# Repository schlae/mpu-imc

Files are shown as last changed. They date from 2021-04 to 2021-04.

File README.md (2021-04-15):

# Roland MPU-IMC Clone

**Warning: There is not enough information in this repository to build your
own card. The microcontroller, IC3, has not been dumped, and the logic in
the gate array chip, IC2, is unknown.**

Based on information available in the MPU-IMC service manual, here is an
exact copy of the board layout. The MIDI Processing Unit is a way to connect
digital musical instruments to a computer using the IBM MCA bus.

Further details on the card are available [here](http://ohlandl.ipv7.net/sound/Roland_MPU-IMC.html).

There are two versions of this board in this repository. The first is a clone
of the stock MPU-IMC. The second is a version that incorporates the circuitry
of the external breakout box normally required for the MPU-IMC, including
the optocoupler required by the MIDI specification.

If you're not sure which board you want to build, choose the modified card.
It has several advantages:

1. You will not need the external Roland breakout box.
2. You can use the card bracket from a common IBM token-ring network card.
3. The DE-9 connector uses the more common footprint.

There are some important caveats with this board set:

1. IC2, the HG62E08, is a gate array chip customized by Roland. Think of it
like a small CPLD but hard coded in ROM. I have no information on the internal
schematic. Beware: not all HG62E08 parts will implement the same exact functions.
Look for a Roland house part number, and make sure they match.
2. IC3, the HD6801VD855P, is a custom mask-programmed microcontroller that
runs the whole show. I have no ROM for this microcontroller.
Before paying for expensive PC boards, make sure you have these chips first!
3. The original (but **NOT** the modded card) has been built and works, see this
[thread on Vogons](https://www.vogons.org/viewtopic.php?f=62&t=77197). The
previous revision accidentally swapped pins 26 and 25 on IC3. This has been
corrected for both the original and the modded card.

For fabrication, use a 2-layer process. You must specify a 30-degree edge bevel,
other angles are probably OK but **do not fab without a bevel at all because
this may damage your MCA bus connectors!** Technically you should get hard gold
for the edge fingers, but that's usually expensive and immersion gold works
just fine.

## MPU-IMC (Plain)

Following are reference materials for your convenience.

[Schematic](https://github.com/schlae/mpu-imc/blob/master/StockCard/RolandMpuImc.pdf)

[Bill of materials](https://github.com/schlae/mpu-imc/blob/master/StockCard/RolandMpuImc.csv)

[Fab files](https://github.com/schlae/mpu-imc/raw/master/StockCard/fab/RolandMpuImc.zip)

**Please note that the DE-9 connector is NOT the standard connector commonly
available**--the distance between the mounting holes and the front plane of
the connector is somewhat larger than usual. You may have to search surplus
sources to find one that will fit, or modify the footprint.

## MPU-IMC (Modified)

Following are reference materials for your convenience.

[Schematic](https://github.com/schlae/mpu-imc/blob/master/ModdedCard/RolandMpuImcMod.pdf)

[Bill of materials](https://github.com/schlae/mpu-imc/blob/master/ModdedCard/RolandMpuImcMod.csv)

[Fab files](https://github.com/schlae/mpu-imc/raw/master/ModdedCard/fab/RolandMpuImcMod.zip)

The DE-9 connector uses the industry standard footprint and is readily available from Mouser.
It's been relocated so that the card bracket from an IBM token ring network card (74F9321)
will fit.

# License

This work is licensed under a Creative Commons Attribution 4.0 International License. See [https://creativecommons.org/licenses/by/4.0/](https://creativecommons.org/licenses/by/4.0/).

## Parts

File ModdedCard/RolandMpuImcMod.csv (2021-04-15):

Item | Qty | Reference(s) | Value | LibPart | Footprint | Datasheet | Mouser
1 | 20 | C1, C3, C4, C6, C7, C8, C9, C10, C11, C12, C13, C14, C15, C18, C19, C24, C26, C29, C31, C35 | 0.1 | Device:C_Small | Roland:C_DISC_200 |  | 581-SR215E104MAT
2 | 4 | C2, C16, C23, C33 | 100/6.3 | Device:CP1_Small | Roland:C_RADIAL_200_P |  | ECA-0JM101B
3 | 1 | C17 | 0.033 | Device:C_Small | Roland:C_DISC_200 |  | 581-SR215C333K
4 | 2 | C20, C30 | 0.0047 | Device:C_Small | Roland:C_DISC_200 |  | 581-SR215C472KAA
5 | 1 | C21 | 0.018 | Device:C_Small | Roland:C_DISC_200 |  | 581-SR215C153KAR
6 | 1 | C22 | 0.0039 | Device:C_Small | Roland:C_DISC_200 |  | 581-SR215C332KAR
7 | 1 | C25 | 22p | Device:C_Small | Roland:C_DISC_200 |  | 581-SR215A220KARTR1
8 | 1 | C27 | 0.0068 | Device:C_Small | Roland:C_DISC_200 |  | 581-SR215C682KAR
9 | 1 | C28 | 0.027 | Device:C_Small | Roland:C_DISC_200 |  | 581-SR211E273M
10 | 1 | C32 | 15p | Device:C_Small | Roland:C_DISC_200 |  | 581-SR211A150KAR
11 | 1 | C34 | 0.001 | Device:C_Small | Roland:C_DISC_200 |  | 581-SR215C102JAR
12 | 2 | C5A1, C5B1 | C_Small | Device:C_Small | Roland:C_DISC_200 |  | 581-SR211A150KAR
13 | 2 | D1, D2 | ? | Device:D_Small_ALT | Roland:D_200 |  | 512-1N4148
14 | 1 | D3 | 1S2473 | Device:D_Small_ALT | Roland:D_200 |  | 512-1N4148
15 | 9 | FL1, FL2, FL3, FL4, FL5, FL6, FL7, FL8, FL9 | EMI_Filter_C | Device:EMI_Filter_C | Roland:FILT_200 |  | 652-EMI101T-RC
16 | 1 | IC1 | LC3517 (or HY6116AP-10) | Roland:LC3517 | Active:DIP254P1524X635-24
17 | 1 | IC2 | HG62E08 | Roland:HG62E08 | Roland:TQFP-64
18 | 1 | IC3 | HD6801VD855P | Roland:HD6801VD855P | Active:DIP254P1524X635-40
19 | 2 | IC4, IC6 | 74LS05 | RolandMpuImcMod-rescue:74LS05 | Active:DIP254P762X635-14 |  | 595-SN74LS05N
20 | 1 | IC5 | 74LS02 | RolandMpuImcMod-rescue:74LS02 | Active:DIP254P762X635-14 |  | 595-SN74LS02N
21 | 1 | IC7 | 74LS32 | RolandMpuImcMod-rescue:74LS32 | Active:DIP254P762X635-14 |  | 595-SN74LS32N
22 | 1 | IC8 | 74LS04 | RolandMpuImcMod-rescue:74LS04 | Active:DIP254P762X635-14 |  | 595-SN74LS04N
23 | 1 | IC9 | 74LS74 | RolandMpuImcMod-rescue:74LS74 | Active:DIP254P762X635-14 |  | SN74LS74AN
24 | 1 | IC10 | 74LS138 | RolandMpuImcMod-rescue:74LS138 | Active:DIP254P762X635-16 |  | 595-SN74LS138N
25 | 1 | IC11 | 74ALS573 | RolandMpuImcMod-rescue:74LS573 | Active:DIP254P762X635-20 |  | 595-SN74ALS573CN
26 | 1 | IC12 | 74LS86_P | Roland:74LS86_P | Active:DIP254P762X635-14 |  | 595-SN74LS86AN
27 | 2 | IC13, IC15 | 74LS688 | RolandMpuImcMod-rescue:74LS688 | Active:DIP254P762X635-20 |  | 595-SN74LS688N
28 | 1 | IC14 | HEF4093B | RolandMpuImcMod-rescue:HEF4093B | Active:DIP254P762X635-14 |  | 595-CD4093BE
29 | 1 | IC16 | 5218 | RolandMpuImcMod-rescue:LM2904 | Active:DIP254P762X635-8 |  | 595-TLV2362IP
30 | 1 | IC17 | H11L1 | RolandMpuImcMod-rescue:H11L1 | Active:DIP254P762X635-6 |  | 512-H11L1TVM
31 | 1 | IRQ1 | Conn_02x06_Odd_Even | RolandMpuImcMod-rescue:Conn_02x06_Odd_Even | Pin_Headers:Pin_Header_Straight_2x06_Pitch2.54mm
32 | 1 | J1 | DB9_Female_MountingHoles | RolandMpuImcMod-rescue:DB9_Female_MountingHoles | Roland:DE-9B |  | 571-2311765-1
33 | 1 | J2 | BUS_MCA | Roland:BUS_MCA | Roland:BUS_MCA_ROLAND
34 | 4 | J3, J4, J5, J6 | Conn_01x01 | RolandMpuImcMod-rescue:Conn_01x01 | Mounting_Holes:MountingHole_3.2mm_M3
35 | 1 | L2 | BL02RN2-R62 | Device:L_Core_Ferrite_Small | Roland:FERR_200 |  | 81-BL03RN2R1P1A
36 | 5 | Q1, Q2, Q3, Q4, Q5 | 2SC1815 | RolandMpuImcMod-rescue:2SC1815 | Roland:Q_200_J |  | 610-2SC1815
37 | 10 | R1, R3, R7, R8, R9, R10, R11, R13, R31, R44 | 4.7K | Device:R_Small | Roland:R_AXIAL_200 |  | 603-CFR-12JB-52-4K7
38 | 8 | R2, R22, R23, R27, R28, R29, R36, R41 | 10K | Device:R_Small | Roland:R_AXIAL_200 |  | 603-CFR-12JB-52-10K
39 | 5 | R4, R5, R17, R25, R30 | 33K | Device:R_Small | Roland:R_AXIAL_200 |  | 603-CFR-12JB-52-33K
40 | 1 | R6 | 1M | Device:R_Small | Roland:R_AXIAL_200 |  | 603-CFR-12JB-52-1M
41 | 1 | R12 | 100 | Device:R_Small | Roland:R_AXIAL_200 |  | 603-CFR-12JB-52-100R
42 | 1 | R14 | 82K | Device:R_Small | Roland:R_AXIAL_200 |  | 603-CFR-12JB-52-82K
43 | 1 | R15 | 22K | Device:R_Small | Roland:R_AXIAL_200 |  | 603-CFR-12JB-52-22K
44 | 1 | R16 | 47K | Device:R_Small | Roland:R_AXIAL_200 |  | 603-CFR-12JB-52-47K
45 | 2 | R18, R20 | 180 | Device:R_Small | Roland:R_AXIAL_200 |  | 603-CFR-12JB-52-180R
46 | 2 | R19, R35 | 1K | Device:R_Small | Roland:R_AXIAL_200 |  | 603-CFR-12JB-52-1K
47 | 1 | R21 | 6.8K | Device:R_Small | Roland:R_AXIAL_200 |  | 603-CFR-12JB-52-6K8
48 | 1 | R24 | 820K | Device:R_Small | Roland:R_AXIAL_200 |  | 603-CFR-12JB-52-820K
49 | 1 | R26 | 470K | Device:R_Small | Roland:R_AXIAL_200 |  | 603-CFR-12JR-52-470K
50 | 2 | R32, R33 | 470 | Device:R_Small | Roland:R_AXIAL_200 |  | 603-CFR-12JB-52-470R
51 | 2 | R34, R43 | 100K | Device:R_Small | Roland:R_AXIAL_200 |  | 603-CFR-12JB-52-100K
52 | 1 | R37 | 270 | Device:R_Small | Roland:R_AXIAL_200 |  | 603-CFR-12JB-52-270R
53 | 3 | R38, R39, R40 | 220 | Device:R_Small | Roland:R_AXIAL_200 |  | 603-CFR-12JB-52-220R
54 | 1 | RA1 | R_Network08 | Device:R_Network08 | Resistors_THT:R_Array_SIP9 |  | 652-4609X-1LF-33K
55 | 1 | X1 | Crystal | Device:Crystal | Roland:Y_200 |  | 520-HCU400-20X

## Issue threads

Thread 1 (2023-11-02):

IC2 6801V0B55P is dumped and more info

matt713, 2023-11-02:
hi Eric, I just want to let you know that 6801V0B55P was dumped 10 years ago, I posted details here:

https://www.vogons.org/viewtopic.php?p=1202055#p1202055

and here:

https://www.vogons.org/viewtopic.php?f=62&t=96744

that dump is the latest known ROM for 6801V0B55P, i.e. version 1.5A, but 6801V0B55P with ROM version 1.4B is confirmed to exist in the wild, at least based on one report:

https://forum.vcfed.org/index.php?threads/roland-mpu-401-eprom-upgrade-1-5a.1238114/

in short that means command 0xAC returns 15 or 14 (respectively version 1.5 or 1.4) and command 0xAD returns 1 or 2 (respectively revision 'A' or 'B' to designate 1.5A or 1.4B) :

https://www.vogons.org/viewtopic.php?p=1202056#p1202056

the retro-computing community believes that 1.5A is the latest Intelligent MIDI firmware version, because that is what is also documented in the "MPU-401 Technical Reference Manual", but now, based on few findings that I made very recently,  I have very strong evidence that there are newer firmware versions (and most importantly those new versions are for Generic 6801 and not for the custom and unobtainable now Roland part 6801V0B55P). it seems those newer firmware versions were introduced to existing devices mainly when an MPU-401 unit was sent back to Roland for a repair, which as you will see makes a lot of sense and here is how I came to that conclusion in chronological order:

thanks to a family friend, now a very old gentleman, who owns that particular MPU-401 unit since like 40 years, I was able to find out that unit has firmware which returns:

0xAC --> 0x15
0xAD --> 0x39

at first I was shocked and confused by that, as there is no known revision 0x39 of firmware 1.5, the only known one is revision 1, i.e. 1.5A.

that's why initially, I was thinking that it has to be some fault like maybe some bits flipped due to aging process where value '01' is stored in the ROM and it became '39', but digging further and further, as it will become clear below, showed me that is not the case and the firmware is really "1.5 revision 39".

What was even more confusing is that based on the label sticker on the bottom of the unit, it shows the unit is from May 1984, i.e. very very early unit, actually one of the earliest possible units - that is over 1 year before Roland released firmware 1.5, which release date is documented in "MPU-401 Technical Reference Manual" to be May 31, 1985.

So, based on "May 1984" date, what it should have is firmware 1.2, but yet it has 1.5 with some strange 0x39 revision number.

OK, it will be long, but digging deeper - I told the owner what I found out and how confusing it is and he told me the unit was sent back to Roland (he cannot recall the exact date or year) for a repair. So, I opened the unit and it was full of surprises:

* what I immediately noticed is the sticker on the EPROM chip - the "2" is stroked-through with an X and "5" is marked, which suggested to me that is how they designated the unit was version 1.2 and it's upgraded to 1.5 during the repair process plus one corner (bottom left) of the sticker shows clear signs of how it was peeled in order to erase it with UV light, finally not one, but several things that seem to add up and to make a lot of sense, here is high-res picture of that EPROM:

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

* Still, I was not sure that is really how they indicate the version on the EPROM sticker, i.e. if for example "5" marked is really supposed to mean version 1.5 and I needed to find some more evidence to support that. So, after spending a lot of time searching for pictures online of another unit with EPROM chip the only one I found is this one:

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

at first that picture added some doubts to me, because it has "7" marked on the EPROM sticker, i.e. if my hypothesis is correct then that should mean firmware version 1.7, which is another unheard thing, but it took me almost no time searching to find that Vogons user "cricket" reported 5 years ago he has unit with ROM version 1.7C, as the post says:

> I can use MPUTHRU.COM on the unit and it prints ROM version 1.7C

https://www.vogons.org/viewtopic.php?p=681558#p681558

even it seems back then no one really paid much attention that version 1.7C is something actually new and unheard.

It's also important that the unit from the picture above with "7" marked on the EPROM is not using 6801V0B55P, but another chip 6801V0A88P, which adds up - different chip, different ROM version, i.e. 1.7C that is not seen on units with 6801V0B55P that are 1.4B or 1.5A.

* further more and it was the final nail in the coffin so to speak is my investigation is that another Vogons user "Artex", reported 10 years ago unit with sticker on the EPROM chip saying "Roland 1.5 DB" :

https://www.vogons.org/viewtopic.php?p=296139#p296139

that to me indicates "version 1.5 revision DB"

here are the 2 important parts of that post:

> two chips missing on the PCB that are present on mine

"Artex" meant by that the EPROM chip and HD74LS04P, which are missing on most MPU-401 units, i.e. those with 6801V0B55P, which has build-in ROM and thus no external EPROM chip.

and "Artex" added:

> The bigger chip says "Roland 1.5 DB"

and between HD74LS04P and the EPROM chip, the bigger one is the EPROM, i.e. "Artex" no doubt is talking about the sticker on the EPROM chip and that it's "Roland 1.5 DB" or "version 1.5 revision DB" (I guess that is the moment when they switched to that new format of the sticker)

Summary and final words:

it seems there are 3 designs:

* 6801V0B55P (build-in ROM, latest known version 1.5A, dumped 10 years ago by the MAME project), in this case the EPROM and HD74LS04P are not populated on the board, but there is space left for them (I guess especially useful when repair is needed).

* 6801V0A88P + HD74LS04P + EPROM : latest known ROM version is 1.7C, unfortunately, dump is not available and Vogons user "cricket" that seems to have such unit is not active for years, i.e. cannot be reached. in any case I don't believe that case is important, because still 6801V0A88P is Roland part and unobtainable now

* the most important and very interesting case - the case of that started my investigation. it's so interesting, because it doesn't use Roland part, but instead off-the-shelf or regular/generic 6801 micro-controller + HD74LS04P + EPROM, i.e. design that is replicate-able. it seems ROM in my case is "version 1.5 revision 39", but there is "version 1.5 revision DB", i.e. the latest known as per the post of user "Artex" on Vogons. Too bad, "Artex" seems is not active for years on Vogons and no dump of that "version 1.5 revision DB".

Another interesting thing is that disassembling 6801V0B55P ROM 1.5A and the dump I made of "version 1.5 revision 39" from that repaired unit with the regular/generic 6801 micro-controller shows different instructions are used - few examples:

LDAB (1.5A) --> LDB (1.5 rev 39)
LDAA (1.5A) --> LDA (1.5 rev 39)
STAA (1.5A) --> STA (1.5 rev 39)

and so and so on. Now, I know nothing about 680x-assembler and it took me a lot of searching to find out this:

http://datapipe-blackbeltsystems.com/windows/flex/asm4.html

which states:

> SOURCE FORM: LDA (P); LDB (P);
> 6800 ALTERNATES: LDAA (P); LDAB (P);

and

> SOURCE FORM: STA (P);
> 6800 ALTERNATES: STAA (P);

or it seems "1.5 rev 39" is compiled as 6809-code, which I don't really get, because the PCB with that ROM has off-the-shelf regular/generic 6801 micro-controller. In any case, it seems as part of repairs (and I guess lack of stock of those custom Roland 6801V0B55P or 6801V0A88P parts), they replaced the chip with regular/generic 6801 and built that "1.5 rev 39" firmware. Something almost like Roland hacked themselves. Again, it's too bad Vogons user "Artex" is unreachable and we cannot learn more about that "version 1.5 revision DB" unit and what chip it has inside.
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
schlae, 2023-11-09:
wow, incredible research! it should be possible to reimplement the HG62E08R10FS using a CPLD, or perhaps a small FPGA. the next step would be to reverse engineer and comment the firmware to (as you mentioned) understand how the gate array is supposed to work.

matt713, 2023-11-20:
please, if I can further help with anything feel free to emails me: matura713@gmail.com.

schlae, 2023-11-21:
i won't be able to look into this for quite some time since i am busy with other projects. but feel free to try your hand at reverse engineering the firmware that you've dumped.

matt713, 2023-11-21:
actually, the MAME source code:

https://github.com/mamedev/mame/blob/master/src/devices/machine/mpu401.cpp

gives good idea how at least the gate array and the 6801 micro-controller are communicating. what I am not sure is if the speed in their code is correct, because MAME code says "/* 4 MHz as per schematics */", but the 6801 micro-controller in my repaired unit is 1MHz. maybe, there is some internal divider or something, i.e. externally it's 4MHz and internally 1MHz, not sure. anyway, just making a note, it's all subject to further in-depth analysis of the firmware code.

matt713, 2023-11-29:
The following is off-topic when it comes to MPU-IMC preservation, but I want to document it here and keep all the information in the same place, because it's on-topic when it comes to designs that were used.

So, I found 4th design, apart from the 3 designs I mentioned in the previous posts ("6801V0B55P with build-in ROM", "6801V0A88P + HD74LS04P + EPROM" and "Generic 6801 MCU + HD74LS04P + EPROM) - that 4th design is highly integrated and I found it in MPU-401N unit that I purchased very cheaply (less than 20 USD) with the sole intent to see what's inside it, because without the very special 110-pin cable that MPU-401N unit needs it's not really usable plus very few NEC PC-98 laptops have such 110-pin connector in the first place.

So, here is what's inside:
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

It's all highly integrated and concentrated in that big chip with the 3 dies located in the right bottom corner of the PCB.

After I de-soldered that chip:
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

it became clear it's "15239182" - that is not only silk-screened on the PCB under the IC, but I can see it when I hold the IC against light as well. BTW, that big capacitor-looking thingy on the bottom side of  "15239182" IC is actually 4MHz crystal - it's written on one of its sides, other small SMD components on the bottom side of "15239182" are nothing special - just few regular resistors and capacitor.

So, after some searching it turned out "15239182" is documented in SCC-1 Service Manual ("ROLAND_SCC-1_SERVICE_NOTES.pdf") and it's described as:

`MPU Core: a hybrid IC integrating the CPU of MPU-PC98II, gate array and RAM. Its operation is fully compatible with MPU-401`

now what is most interesting and the main finding is that makes possible and allows "**Converting MPU-401N to an ISA card**", because SCC-1 Service Manual contains pin-out of "15239182" and even better - full schematic how "15239182" is wired to an ISA bus. it's very simple circuit - essentially, it's consist just of 74HC688 used for port address decoding and "15239182". So, to make ISA Intelligent MPU-401 card around "15239182" requires very few components, because basically "15239182" is System-on-Chip when it comes to  Intelligent MPU-401 processing.

Basically, that 4th design opens up the possibility of making ISA card with recycling mostly useless MPU-401N and use them for a source of "15239182". After all MPU-401N is not very usable otherwise, because its use is limited to very few NEC PC-98 laptops and it requires unobtainable now (and the pin-out is not available anywhere, AFAIK) 110-pin connector cable. So, best use of MPU-401N is converting it to an ISA card using it just as a donor for "15239182" IC and utilizing the schematic from SCC-1 Service Manual. I am planning to make such ISA card for myself, just as a proof-of-concept.

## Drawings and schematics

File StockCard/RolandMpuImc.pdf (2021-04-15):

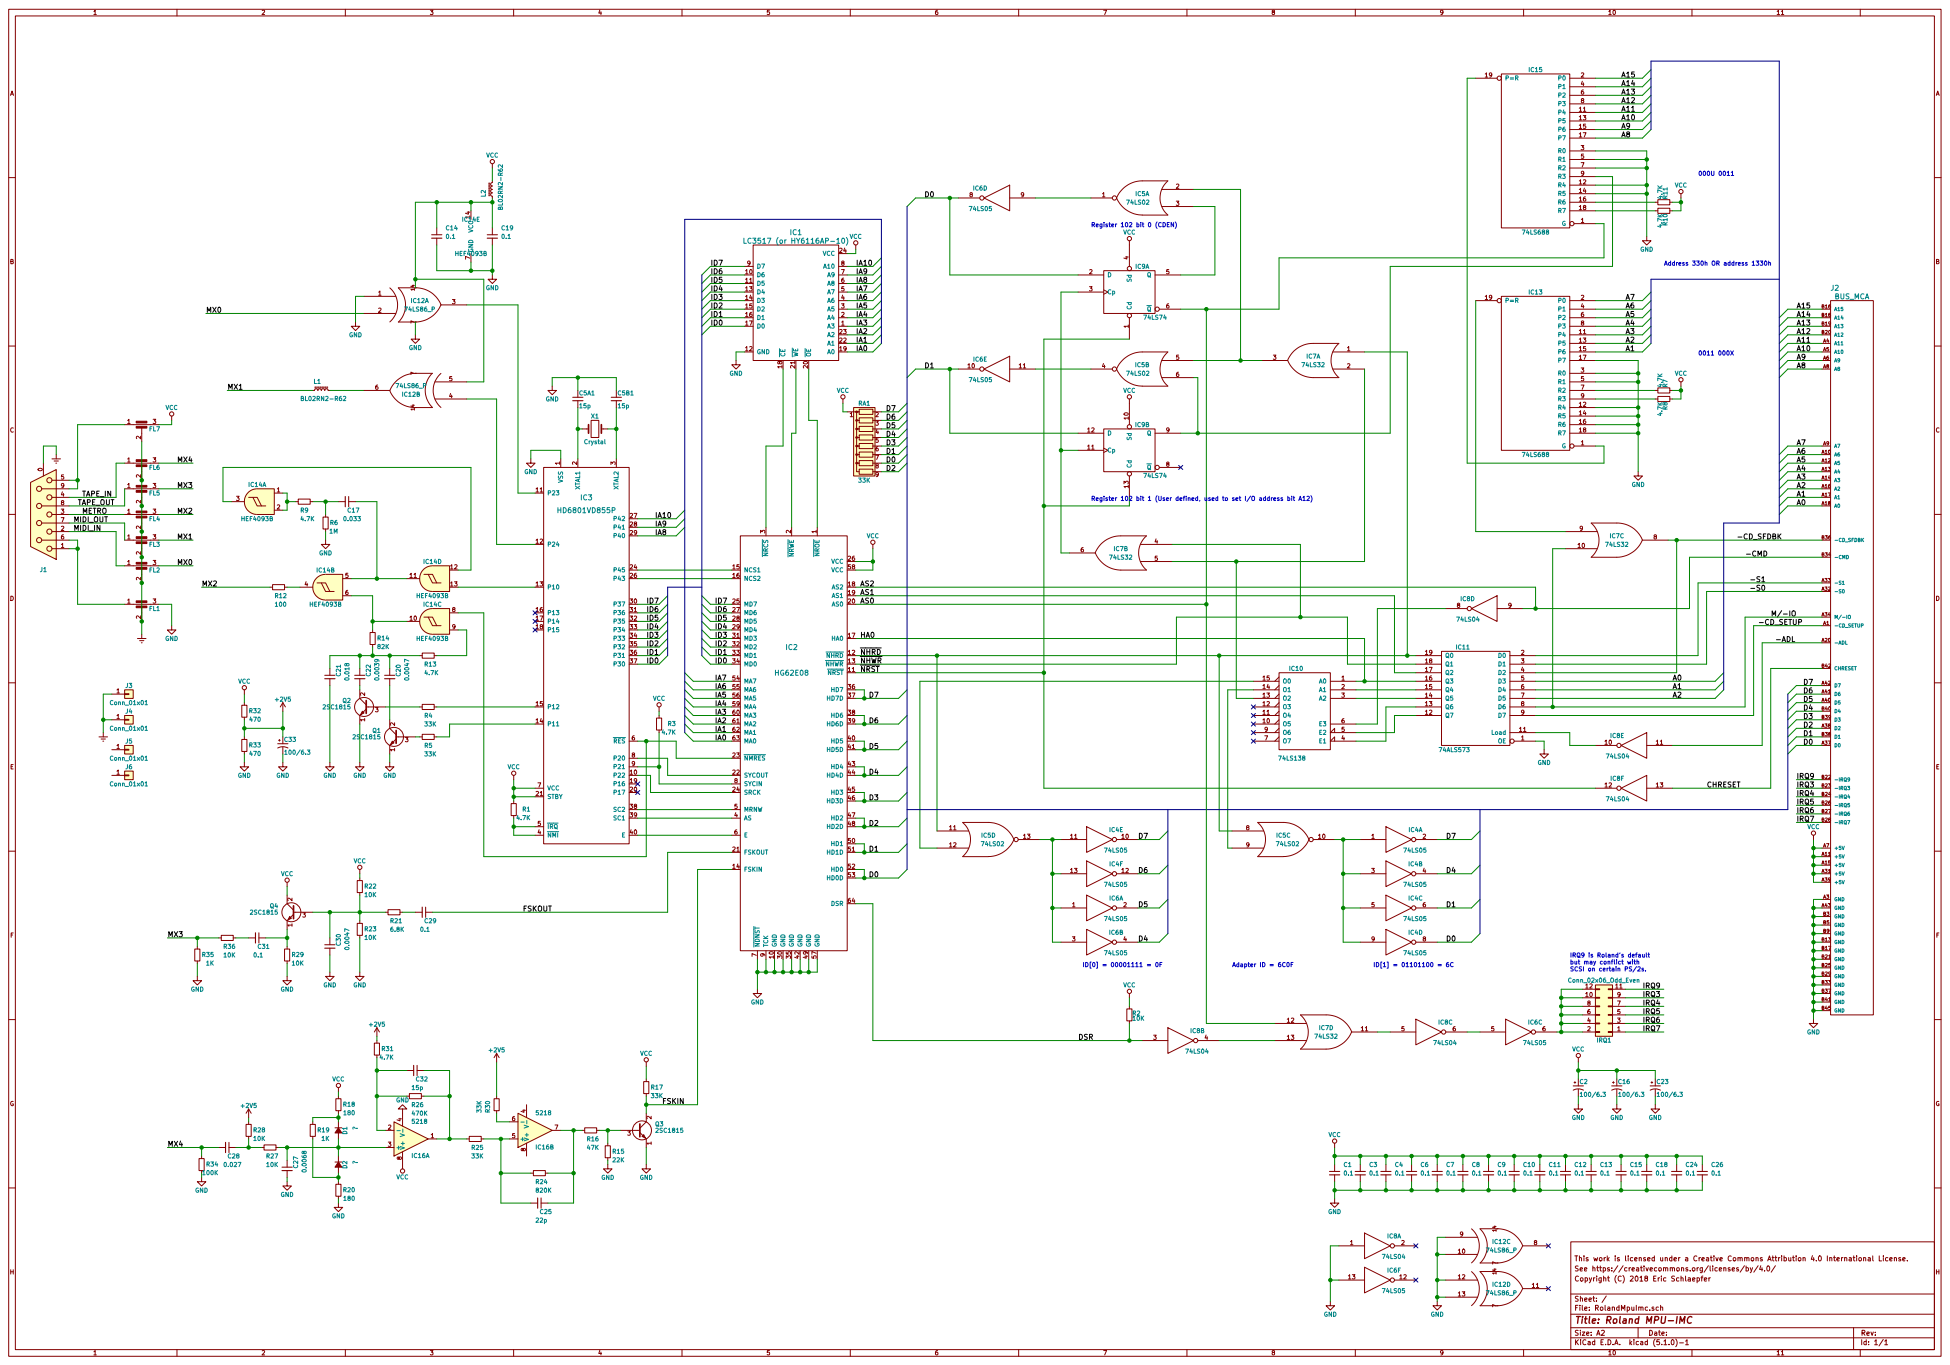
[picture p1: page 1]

ID6 | IA9
ID5 | IA8

ID3 | IA6
ID2 | IA5
ID1 | IA4

Register 102 bit 1 (User defined, used to set I/O address bit A12)

1 GND 10 NRST 11 NHRD 12 NHWR 13 FSKIN 14 NCS1 15 NCS2 16 HA0 17 AS2 18 AS1 19 NRWE

2 AS0 20 FSKOUT 21 SYCOUT 22 NMRES 23 SRCK 24 MD7 25 VCC 26 MD6 27 MD5 28 MD4 29 NRCS

3 GND 30 MD3 31 MD2 32 MD1 33 MD0 34 GND 35 HD7 36 HD7D 37 HD6 38 HD6D 39 AS 4 HD5 40 HD5D 41 GND 42 HD4 43 HD4D 44 HD3 45 HD3D 46 HD2 47 HD2D 48 GND 49 MRNW 5 HD1 50 HD1D 51 HD0 52 HD0D 53 MA7 54 MA6 55 MA5 56 GND 57 VCC 58 MA4 59 E

IRQ9 is Roland's default but may conflict with SCSI on certain PS/2s.

See https://creativecommons.org/licenses/by/4.0/ This work is licensed under a Creative Commons Attribution 4.0 International License.
File: RolandMpuImc.sch Sheet: / Copyright (C) 2018 Eric Schlaepfer

Id: 1/1 Title: Roland MPU-IMC

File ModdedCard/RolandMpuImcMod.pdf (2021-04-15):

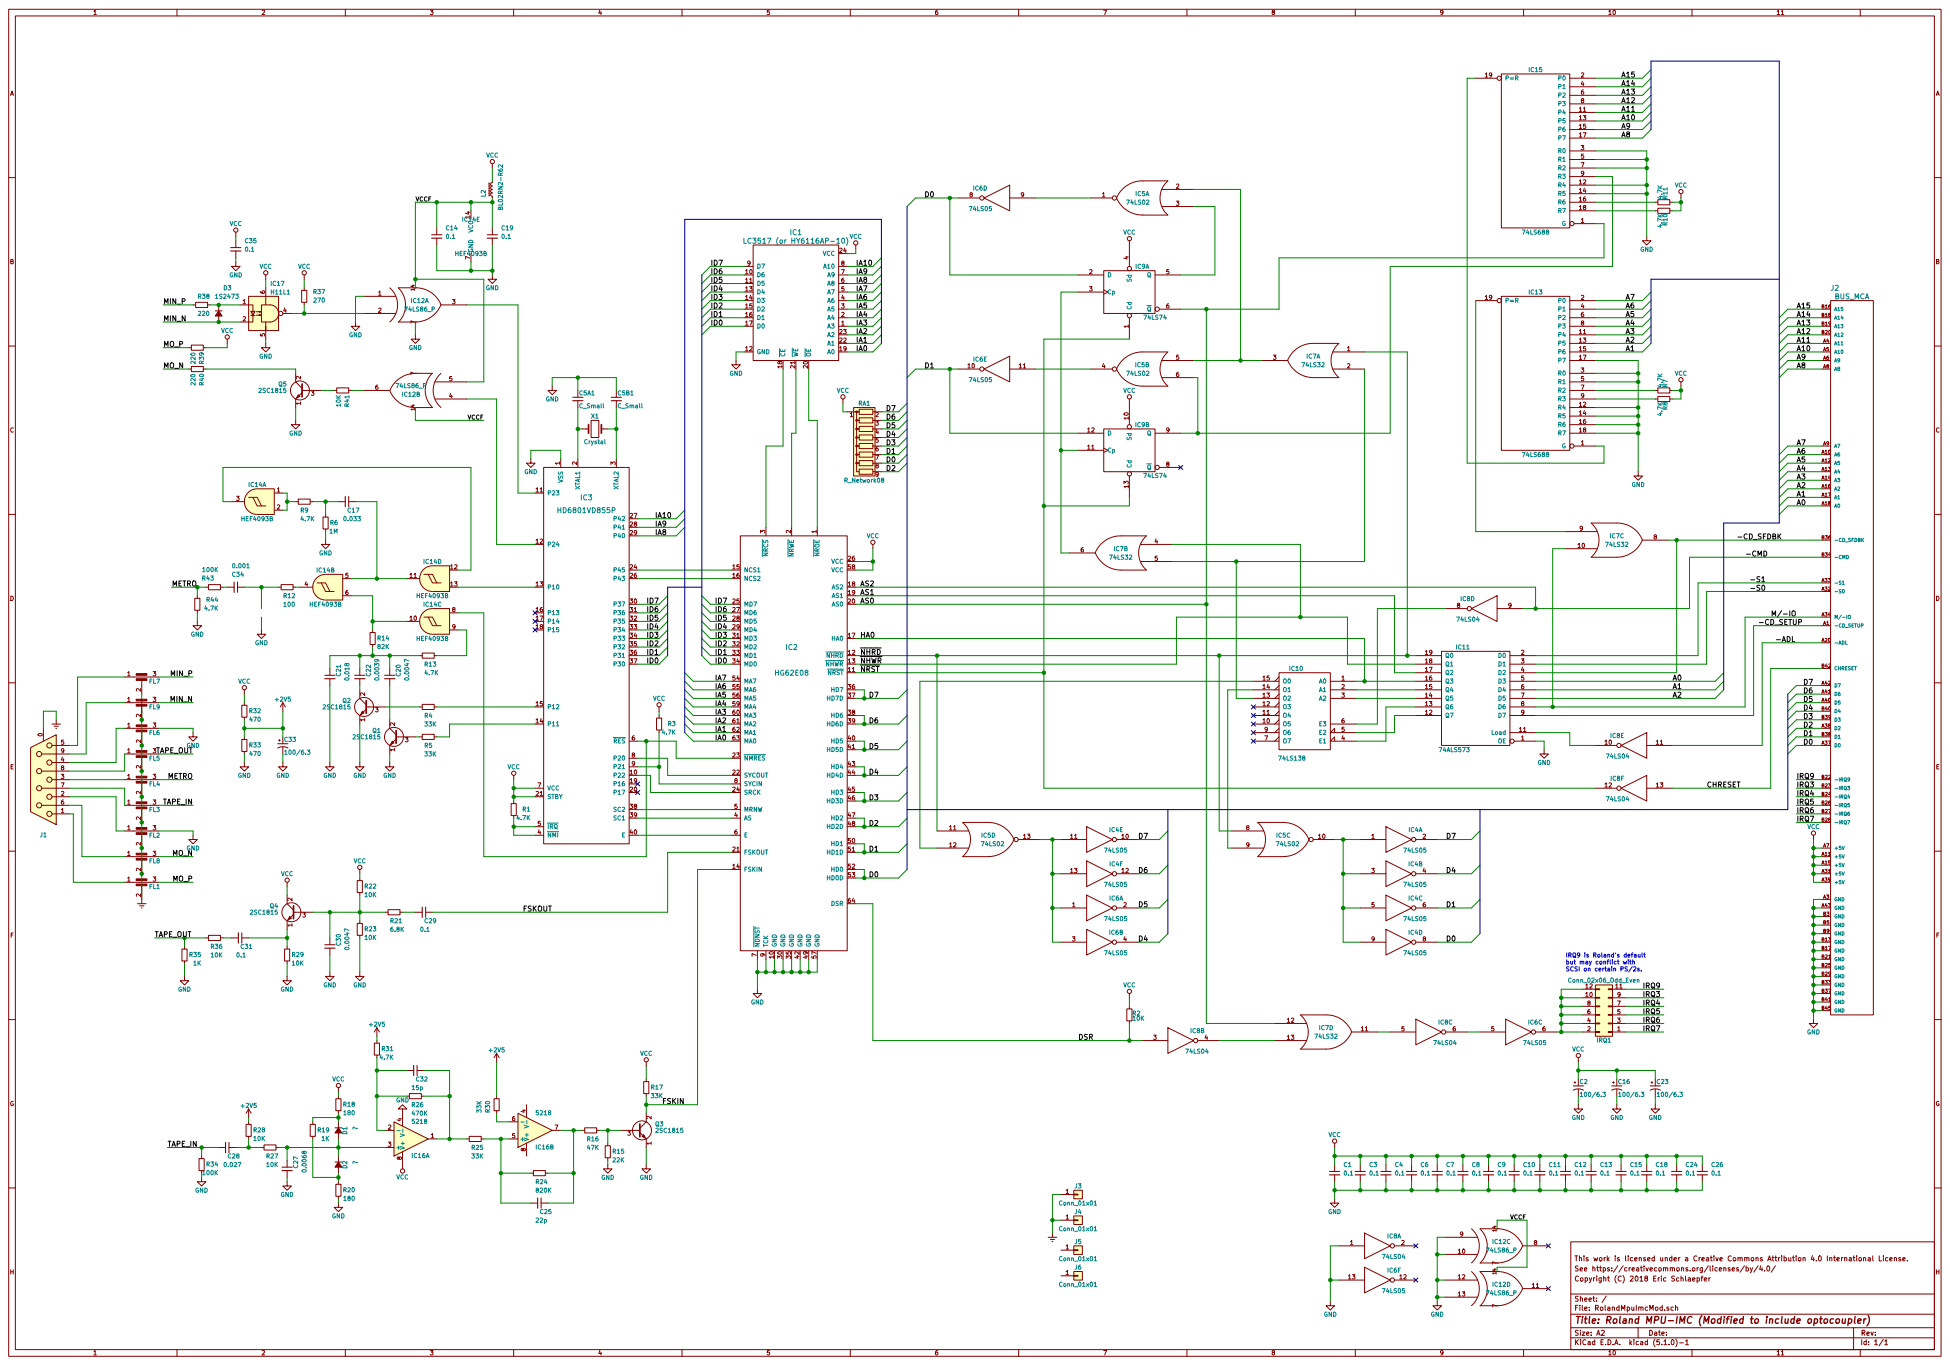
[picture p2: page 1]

ID6 | IA9
ID5 | IA8

ID1 | IA4
ID0 | IA3

IRQ9 is Roland's default but may conflict with SCSI on certain PS/2s.

File: RolandMpuImcMod.sch Sheet: / Copyright (C) 2018 Eric Schlaepfer

Id: 1/1 Title: Roland MPU-IMC (Modified to include optocoupler)

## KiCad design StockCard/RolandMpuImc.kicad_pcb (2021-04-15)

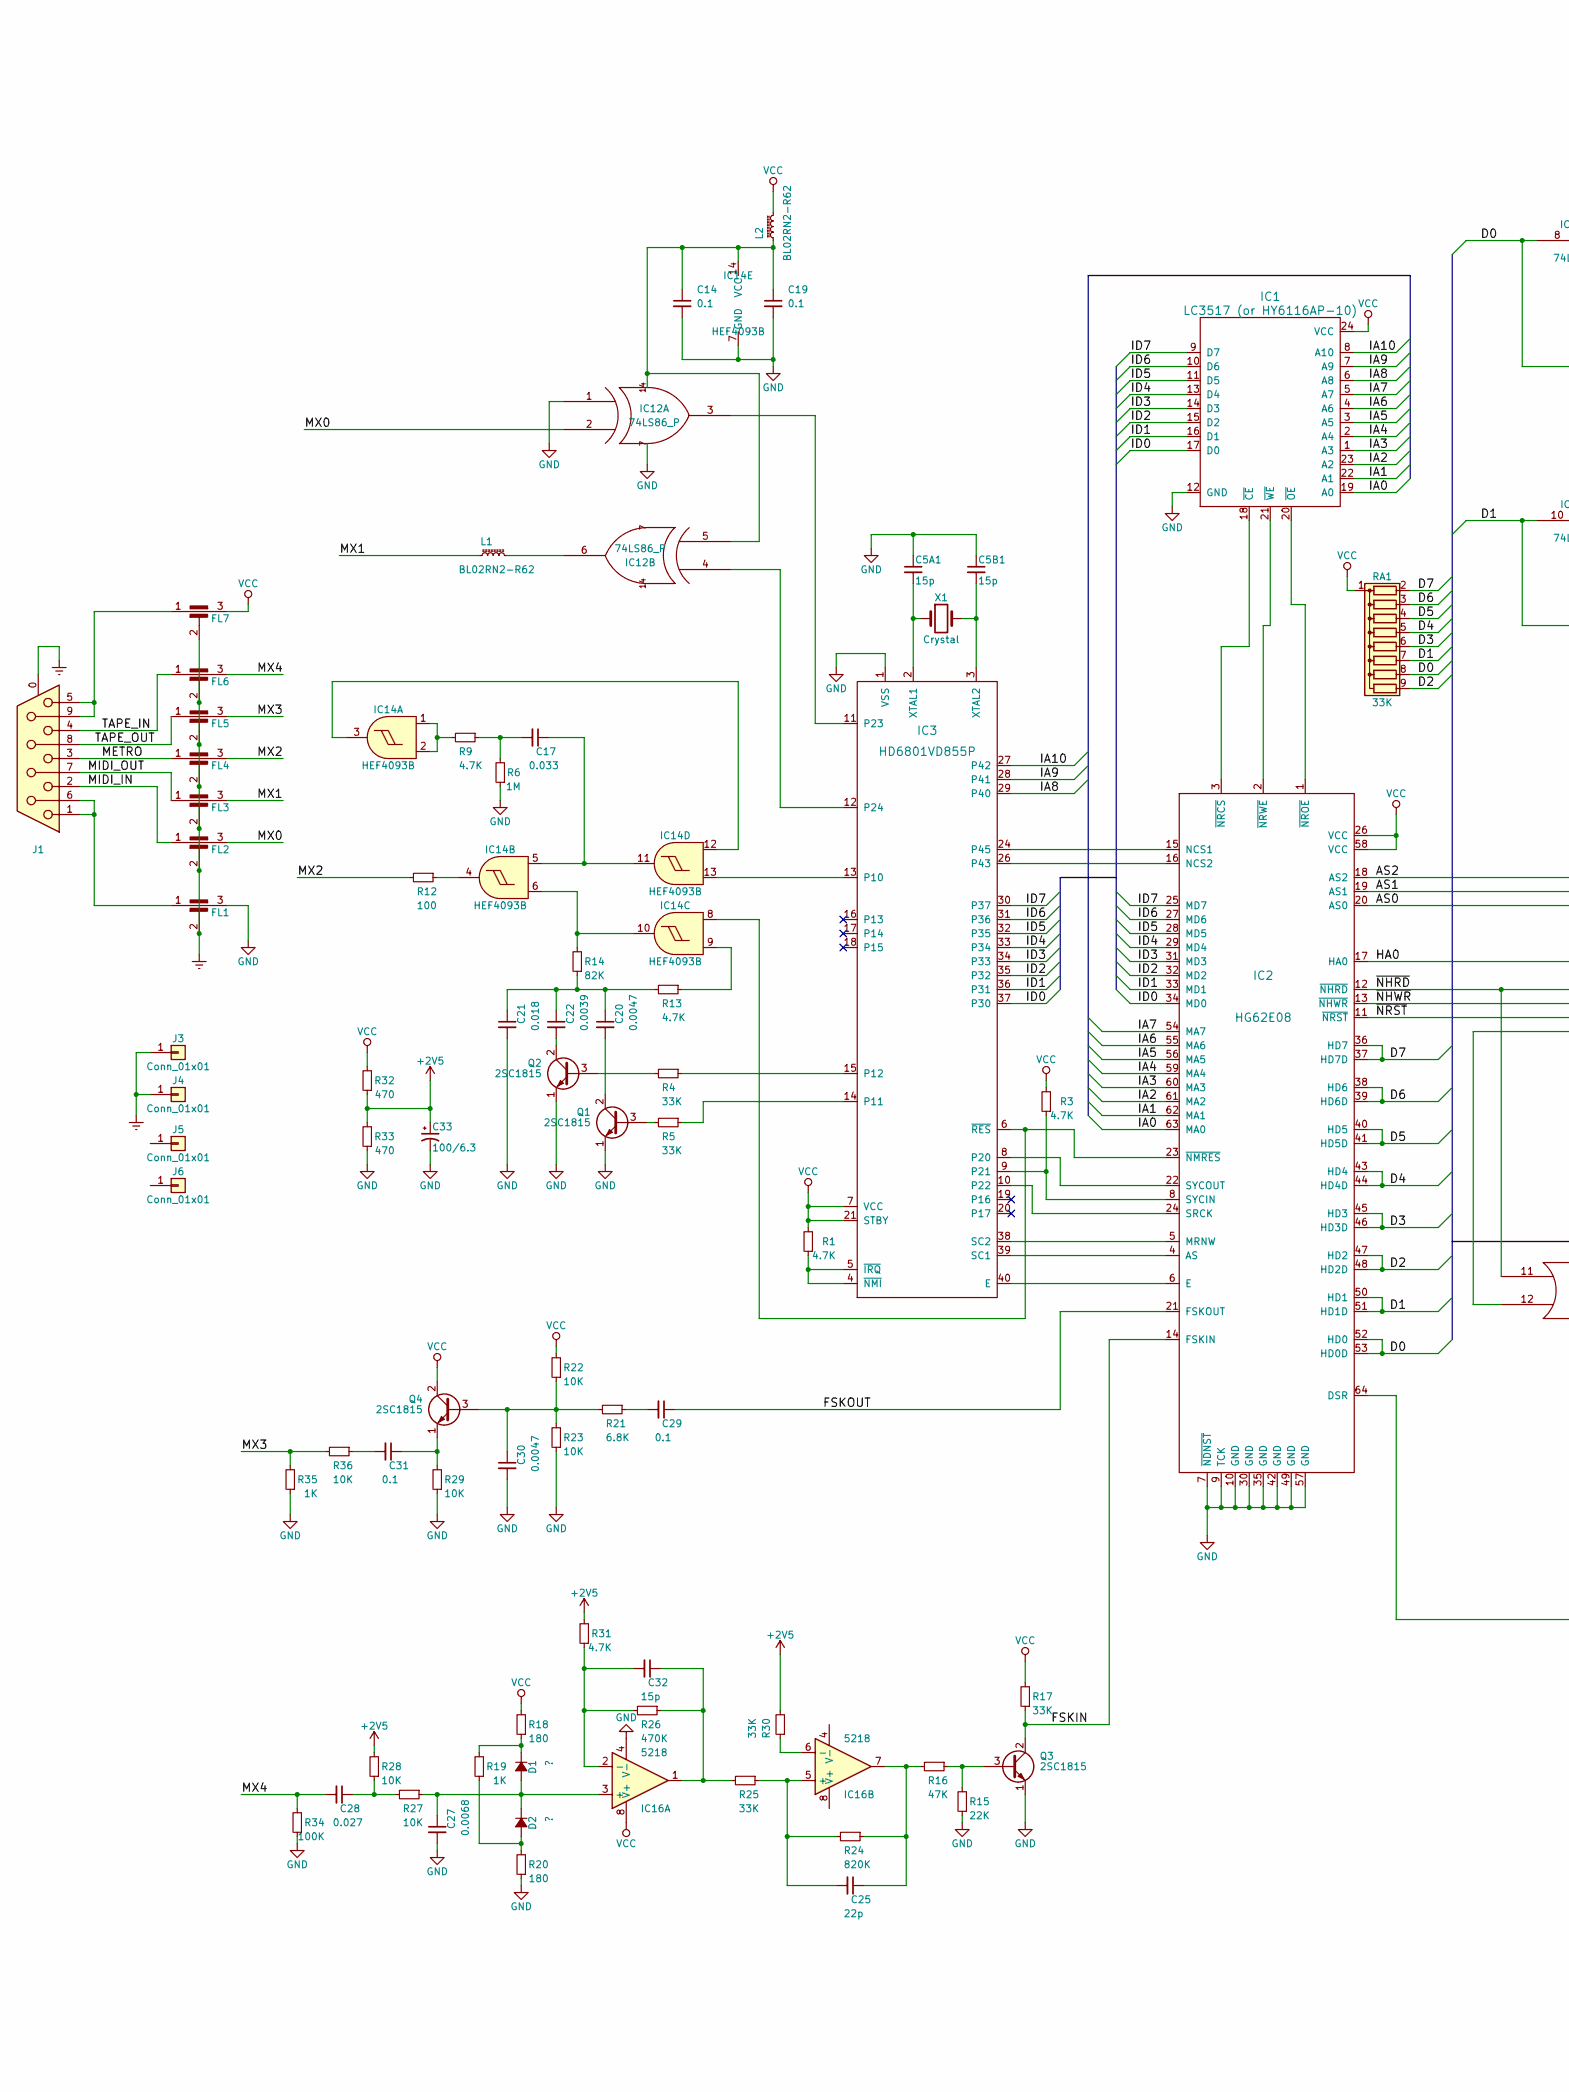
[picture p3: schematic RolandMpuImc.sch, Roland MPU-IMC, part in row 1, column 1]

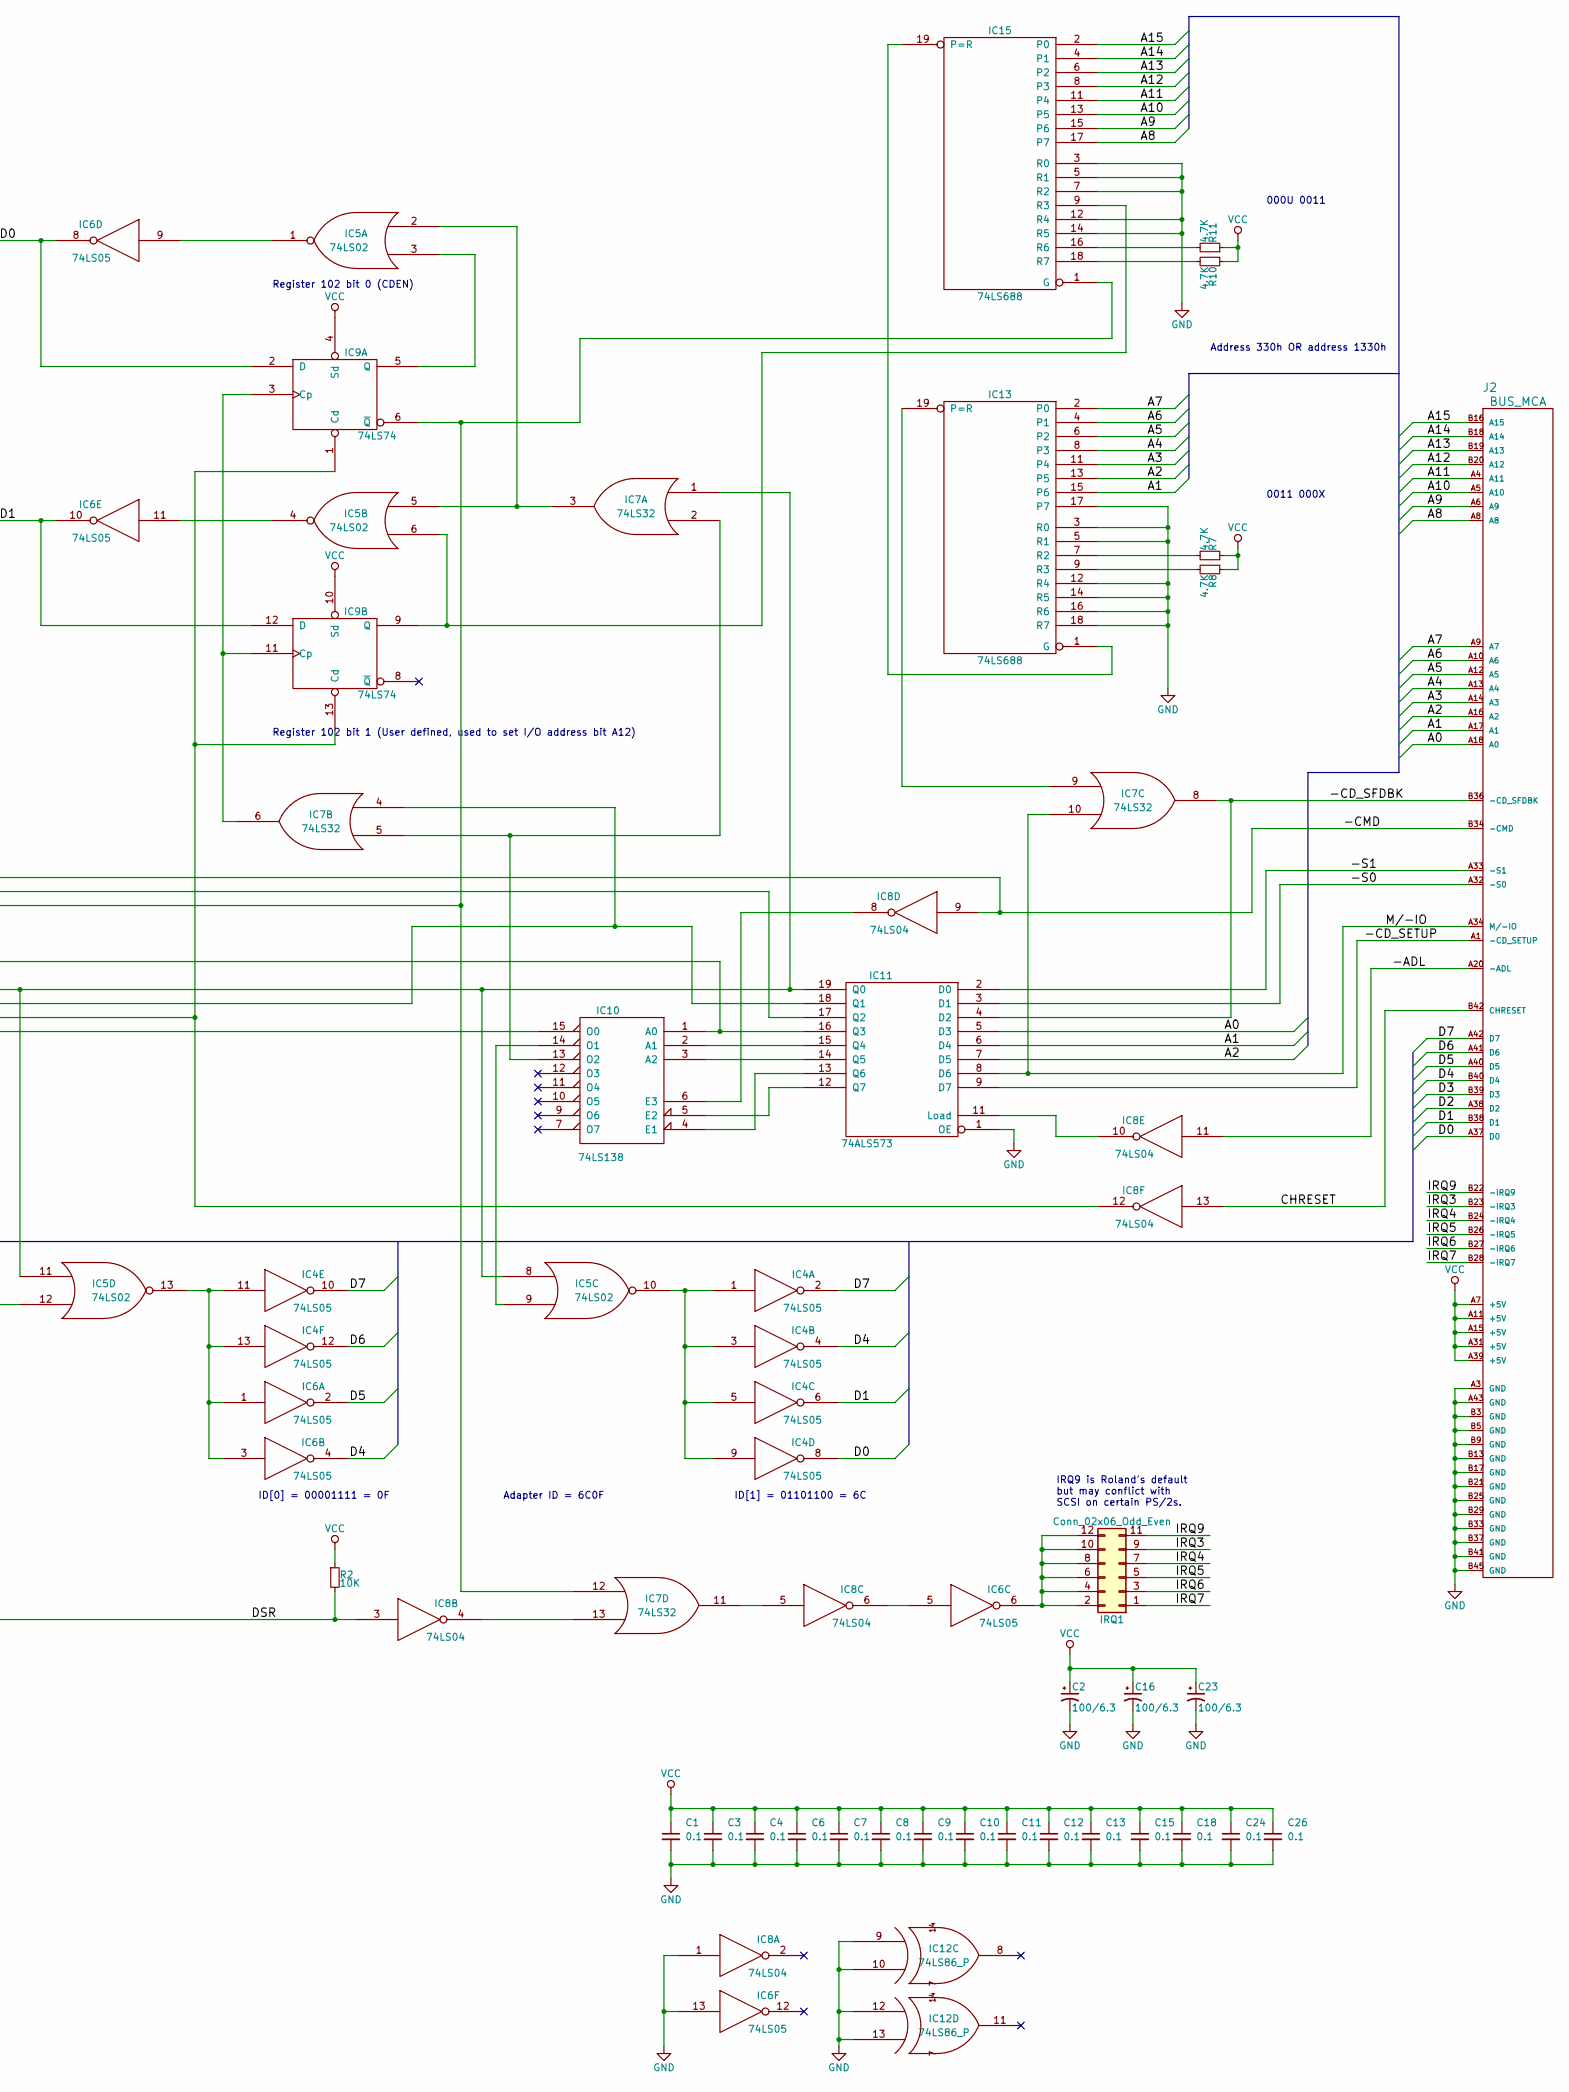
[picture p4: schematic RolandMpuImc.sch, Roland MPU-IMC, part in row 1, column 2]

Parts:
C1, C3, C4, C6, C7, C8, C9, C10, C11, C12, C13, C14, C15, C18, C19, C24, C26, C29, C31: 0.1; C_DISC_200; Mouser 581-SR215E104MAT
C2, C16, C23, C33: 100/6.3; C_RADIAL_200_P; Mouser ECA-0JM101B
C5A1, C5B1, C32: 15p; C_DISC_200; Mouser 581-SR211A150KAR
C17: 0.033; C_DISC_200; Mouser 581-SR215C333K
C20, C30: 0.0047; C_DISC_200; Mouser 581-SR215C472KAA
C21: 0.018; C_DISC_200; Mouser 581-SR215C153KAR
C22: 0.0039; C_DISC_200; Mouser 581-SR215C332KAR
C25: 22p; C_DISC_200; Mouser 581-SR215A220KARTR1
C27: 0.0068; C_DISC_200; Mouser 581-SR215C682KAR
C28: 0.027; C_DISC_200; Mouser 581-SR211E273M
D1, D2: ?; D_200; Mouser 512-1N4148
FL1, FL2, FL3, FL4, FL5, FL6, FL7: EMI_Filter_C; FILT_200; Mouser 652-EMI101T-RC
IC1: LC3517 (or HY6116AP-10); DIP254P1524X635-24
IC2: HG62E08; TQFP-64
IC3: HD6801VD855P; DIP254P1524X635-40
IC4, IC6: 74LS05; DIP254P762X635-14; Mouser 595-SN74LS05N
IC5: 74LS02; DIP254P762X635-14; Mouser 595-SN74LS02N
IC7: 74LS32; DIP254P762X635-14; Mouser 595-SN74LS32N
IC8: 74LS04; DIP254P762X635-14; Mouser 595-SN74LS04N
IC9: 74LS74; DIP254P762X635-14; Mouser SN74LS74AN
IC10: 74LS138; DIP254P762X635-16; Mouser 595-SN74LS138N
IC11: 74ALS573; DIP254P762X635-20; Mouser 595-SN74ALS573CN
IC12: 74LS86_P; DIP254P762X635-14; Mouser 595-SN74LS86AN
IC13, IC15: 74LS688; DIP254P762X635-20; Mouser 595-SN74LS688N
IC14: HEF4093B; DIP254P762X635-14; Mouser 595-CD4093BE
IC16: 5218; DIP254P762X635-8; Mouser 595-TLV2362IP
IRQ1: Conn_02x06_Odd_Even; Pin_Header_Straight_2x06_Pitch2.54mm
J1: DB9_Female_MountingHoles; DE-9; Mouser 523-L77SDE09S1ACH4F
J2: BUS_MCA; BUS_MCA_ROLAND
J3, J4, J5, J6: Conn_01x01; MountingHole_3.2mm_M3
L1, L2: BL02RN2-R62; FERR_200; Mouser 81-BL03RN2R1P1A
Q1, Q2, Q3, Q4: 2SC1815; Q_200_J; Mouser 610-2SC1815
R1, R3, R7, R8, R9, R10, R11, R13, R31: 4.7K; R_AXIAL_200; Mouser 603-CFR-12JB-52-4K7
R2, R22, R23, R27, R28, R29, R36: 10K; R_AXIAL_200; Mouser 603-CFR-12JB-52-10K
R4, R5, R17, R25, R30: 33K; R_AXIAL_200; Mouser 603-CFR-12JB-52-33K
R6: 1M; R_AXIAL_200; Mouser 603-CFR-12JB-52-1M
R12: 100; R_AXIAL_200; Mouser 603-CFR-12JB-52-100R
R14: 82K; R_AXIAL_200; Mouser 603-CFR-12JB-52-82K
R15: 22K; R_AXIAL_200; Mouser 603-CFR-12JB-52-22K
R16: 47K; R_AXIAL_200; Mouser 603-CFR-12JB-52-47K
R18, R20: 180; R_AXIAL_200; Mouser 603-CFR-12JB-52-180R
R19, R35: 1K; R_AXIAL_200; Mouser 603-CFR-12JB-52-1K
R21: 6.8K; R_AXIAL_200; Mouser 603-CFR-12JB-52-6K8
R24: 820K; R_AXIAL_200; Mouser 603-CFR-12JB-52-820K
R26: 470K; R_AXIAL_200; Mouser 603-CFR-12JR-52-470K
R32, R33: 470; R_AXIAL_200; Mouser 603-CFR-12JB-52-470R
R34: 100K; R_AXIAL_200; Mouser 603-CFR-12JB-52-100K
RA1: 33K; R_Array_SIP9; Mouser 652-4609X-1LF-33K
X1: Crystal; Y_200; Mouser 520-HCU400-20X

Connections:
+2V5: C33.1, R28.2, R30.2, R31.2, R32.1, R33.2
/-ADL: IC8.11, J2.A20 (-ADL)
/-CD_SETUP: IC11.9 (D7), J2.A1 (-CD_SETUP)
/-CD_SFDBK: IC7.8, IC11.4 (D2), J2.B36 (-CD_SFDBK)
/-CMD: IC2.18 (AS2), IC8.9, J2.B34 (-CMD)
/-S0: IC11.3 (D1), J2.A32 (-S0)
/-S1: IC11.2 (D0), J2.A33 (-S1)
/A0: IC11.5 (D3), J2.A18 (A0)
/A1: IC11.6 (D4), IC13.15 (P6), J2.A17 (A1)
/A2: IC11.7 (D5), IC13.13 (P5), J2.A16 (A2)
/A3: IC13.11 (P4), J2.A14 (A3)
/A4: IC13.8 (P3), J2.A13 (A4)
/A5: IC13.6 (P2), J2.A12 (A5)
/A6: IC13.4 (P1), J2.A10 (A6)
/A7: IC13.2 (P0), J2.A9 (A7)
/A8: IC15.17 (P7), J2.A8
/A9: IC15.15 (P6), J2.A6 (A9)
/A10: IC15.13 (P5), J2.A5 (A10)
/A11: IC15.11 (P4), J2.A4 (A11)
/A12: IC15.8 (P3), J2.B20 (A12)
/A13: IC15.6 (P2), J2.B19 (A13)
/A14: IC15.4 (P1), J2.B18 (A14)
/A15: IC15.2 (P0), J2.B16 (A15)
/AS0: IC2.20 (AS0), IC7.12, IC9.6 (~Q), IC15.1 (G)
/AS1: IC2.19 (AS1), IC11.17 (Q2)
/CHRESET: IC8.13, J2.B42 (CHRESET)
/D0: IC2.52 (HD0), IC2.53 (HD0D), IC4.8, IC6.8, IC9.2 (D), J2.A37 (D0), RA1.8 (R7)
/D1: IC2.50 (HD1), IC2.51 (HD1D), IC4.6, IC6.10, IC9.12 (D), J2.B38 (D1), RA1.7 (R6)
/D2: IC2.47 (HD2), IC2.48 (HD2D), J2.A38 (D2), RA1.9 (R8)
/D3: IC2.45 (HD3), IC2.46 (HD3D), J2.B39 (D3), RA1.6 (R5)
/D4: IC2.43 (HD4), IC2.44 (HD4D), IC4.4, IC6.4, J2.B40 (D4), RA1.5 (R4)
/D5: IC2.40 (HD5), IC2.41 (HD5D), IC6.2, J2.A40 (D5), RA1.4 (R3)
/D6: IC2.38 (HD6), IC2.39 (HD6D), IC4.12, J2.A41 (D6), RA1.3 (R2)
/D7: IC2.36 (HD7), IC2.37 (HD7D), IC4.2, IC4.10, J2.A42 (D7), RA1.2 (R1)
/DSR: IC2.64 (DSR), IC8.3, R2.2
/FSKIN: IC2.14 (FSKIN), Q3.2 (C), R17.1
/FSKOUT: C29.1, IC2.21 (FSKOUT)
/HA0: IC2.17 (HA0), IC10.1 (A0), IC11.16 (Q3)
/IA0: IC1.19 (A0), IC2.63 (MA0)
/IA1: IC1.22 (A1), IC2.62 (MA1)
/IA2: IC1.23 (A2), IC2.61 (MA2)
/IA3: IC1.1 (A3), IC2.60 (MA3)
/IA4: IC1.2 (A4), IC2.59 (MA4)
/IA5: IC1.3 (A5), IC2.56 (MA5)
/IA6: IC1.4 (A6), IC2.55 (MA6)
/IA7: IC1.5 (A7), IC2.54 (MA7)
/IA8: IC1.6 (A8), IC3.29 (P40)
/IA9: IC1.7 (A9), IC3.28 (P41)
/IA10: IC1.8 (A10), IC3.27 (P42)
/ID0: IC1.17 (D0), IC2.34 (MD0), IC3.37 (P30)
/ID1: IC1.16 (D1), IC2.33 (MD1), IC3.36 (P31)
/ID2: IC1.15 (D2), IC2.32 (MD2), IC3.35 (P32)
/ID3: IC1.14 (D3), IC2.31 (MD3), IC3.34 (P33)
/ID4: IC1.13 (D4), IC2.29 (MD4), IC3.33 (P34)
/ID5: IC1.11 (D5), IC2.28 (MD5), IC3.32 (P35)
/ID6: IC1.10 (D6), IC2.27 (MD6), IC3.31 (P36)
/ID7: IC1.9 (D7), IC2.25 (MD7), IC3.30 (P37)
/IRQ3: IRQ1.9, J2.B23 (-IRQ3)
/IRQ4: IRQ1.7, J2.B24 (-IRQ4)
/IRQ5: IRQ1.5, J2.B26 (-IRQ5)
/IRQ6: IRQ1.3, J2.B27 (-IRQ6)
/IRQ7: IRQ1.1, J2.B28 (-IRQ7)
/IRQ9: IRQ1.11, J2.B22 (-IRQ9)
/M/-IO: IC7.10, IC11.8 (D6), J2.A34 (M/-IO)
/METRO: FL4.1, J1.3
/MIDI_IN: FL2.1, J1.2
/MIDI_OUT: FL3.1, J1.7
/MX0: FL2.3, IC12.2 (IN2)
/MX1: FL3.3, L1.1
/MX2: FL4.3, R12.2
/MX3: FL5.3, R35.2, R36.2
/MX4: C28.2, FL6.3, R34.2
/TAPE_IN: FL6.1, J1.4
/TAPE_OUT: FL5.1, J1.8
/~NHRD: IC2.12 (~NHRD), IC5.8, IC5.11, IC7.1, IC11.19 (Q0)
/~NHWR: IC2.13 (~NHWR), IC7.4, IC11.18 (Q1)
/~NRST: IC2.11 (~NRST), IC8.12, IC9.1 (Cd), IC9.13 (Cd)
Earth: FL1.2, FL2.2, FL3.2, FL4.2, FL5.2, FL6.2, FL7.2, J1.0 (PAD), J3.1, J4.1
GND: C1.2, C2.2, C3.2, C4.2, C5A1.1, C5B1.1, C6.2, C7.2, C8.2, C9.2, C10.2, C11.2, C12.2, C13.2, C14.2, C15.2, C16.2, C18.2, C19.2, C21.2, C23.2, C24.2, C26.2, C27.2, C30.2, C33.2, FL1.3, IC1.12 (GND), IC2.7 (~NDNST), IC2.9 (TCK), IC2.10 (GND), IC2.30 (GND), IC2.35 (GND), IC2.42 (GND), IC2.49 (GND), IC2.57 (GND), IC3.1 (VSS), IC4.7 (GND), IC5.7 (GND), IC6.7 (GND), IC6.13, IC7.7 (GND), IC8.1, IC8.7 (GND), IC9.7 (GND), IC10.8 (GND), IC11.1 (OE), IC11.10 (GND), IC12.1 (IN1), IC12.7 (GND), IC12.9 (IN1), IC12.10 (IN2), IC12.12 (IN1), IC12.13 (IN2), IC13.3 (R0), IC13.5 (R1), IC13.10 (GND), IC13.12 (R4), IC13.14 (R5), IC13.16 (R6), IC13.17 (P7), IC13.18 (R7), IC14.7 (GND), IC15.3 (R0), IC15.5 (R1), IC15.7 (R2), IC15.10 (GND), IC15.12 (R4), IC15.14 (R5), IC16.4 (V-), J2.A3 (GND), J2.A43 (GND), J2.B3 (GND), J2.B5 (GND), J2.B9 (GND), J2.B13 (GND), J2.B17 (GND), J2.B21 (GND), J2.B25 (GND), J2.B29 (GND), J2.B33 (GND), J2.B37 (GND), J2.B41 (GND), J2.B45 (GND), Q1.1 (E), Q2.1 (E), Q3.1 (E), R6.1, R15.1, R20.1, R23.1, R29.1, R33.1, R34.1, R35.1
unnamed: C5A1.2, IC3.2 (XTAL1), X1.1
unnamed: C5B1.2, IC3.3 (XTAL2), X1.2
unnamed: C14.1, C19.1, IC12.5 (IN2), IC12.14 (VCC), IC14.14 (VCC), L2.1
unnamed: C17.1, IC14.5, IC14.11
unnamed: C17.2, R6.2, R9.1
unnamed: C20.1, C21.1, C22.1, R13.2, R14.1
unnamed: C20.2, Q1.2 (C)
unnamed: C22.2, Q2.2 (C)
unnamed: C25.1, IC16.7, R16.2, R24.1
unnamed: C25.2, IC16.5 (+), R24.2, R25.1
unnamed: C27.1, D1.2 (A), D2.1 (K), IC16.3 (+), R27.1
unnamed: C28.1, R27.2, R28.1
unnamed: C29.2, R21.1
unnamed: C30.1, Q4.3 (B), R21.2, R22.1, R23.2
unnamed: C31.1, Q4.1 (E), R29.2
unnamed: C31.2, R36.1
unnamed: C32.1, IC16.1, R25.2, R26.1
unnamed: C32.2, IC16.2 (-), R26.2, R31.1
unnamed: D1.1 (K), R18.1, R19.2
unnamed: D2.2 (A), R19.1, R20.2
unnamed: FL1.1, J1.1, J1.6
unnamed: FL7.1, J1.5, J1.9
unnamed: IC1.18 (~CE), IC2.3 (~NRCS)
unnamed: IC1.20 (~OE), IC2.1 (~NROE)
unnamed: IC1.21 (~WE), IC2.2 (~NRWE)
unnamed: IC2.4 (AS), IC3.39 (SC1)
unnamed: IC2.5 (MRNW), IC3.38 (SC2)
unnamed: IC2.6 (E), IC3.40 (E)
unnamed: IC2.8 (SYCIN), IC3.9 (P21), R3.1
unnamed: IC2.15 (NCS1), IC3.24 (P45)
unnamed: IC2.16 (NCS2), IC3.26 (P43)
unnamed: IC2.22 (SYCOUT), IC3.8 (P20)
unnamed: IC2.24 (SRCK), IC3.10 (P22)
unnamed: IC3.4 (~NMI), IC3.5 (~IRQ), R1.1
unnamed: IC3.14 (P11), R5.1
unnamed: IC3.15 (P12), R4.1
unnamed: IC4.1, IC4.3, IC4.5, IC4.9, IC5.10
unnamed: IC4.11, IC4.13, IC5.13, IC6.1, IC6.3
unnamed: IC5.1, IC6.9
unnamed: IC5.2, IC5.5, IC7.3
unnamed: IC5.3, IC9.5 (Q)
unnamed: IC5.4, IC6.11
unnamed: IC6.5, IC8.6
unnamed: IC6.6, IRQ1.2, IRQ1.4, IRQ1.6, IRQ1.8, IRQ1.10, IRQ1.12
unnamed: IC7.6, IC9.3 (Cp), IC9.11 (Cp)
unnamed: IC7.11, IC8.5
unnamed: IC7.13, IC8.4
unnamed: IC10.2 (A1), IC11.15 (Q4)
unnamed: IC10.3 (A2), IC11.14 (Q5)
unnamed: IC10.4 (E1), IC11.13 (Q6)
unnamed: IC10.5 (E2), IC11.12 (Q7)
unnamed: IC8.8, IC10.6 (E3)
unnamed: IC7.2, IC7.5, IC10.13 (O2)
unnamed: IC5.9, IC10.14 (O1)
unnamed: IC5.12, IC10.15 (O0)
unnamed: IC8.10, IC11.11 (Load)
unnamed: IC3.11 (P23), IC12.3 (OUT)
unnamed: IC3.12 (P24), IC12.4 (IN1)
unnamed: IC12.6 (OUT), L1.2
unnamed: IC13.1 (G), IC15.19 (P=R)
unnamed: IC13.7 (R2), R7.2
unnamed: IC13.9 (R3), R8.2
unnamed: IC7.9, IC13.19 (P=R)
unnamed: IC14.1, IC14.2, R9.2
unnamed: IC14.4, R12.1
unnamed: IC2.23 (~NMRES), IC3.6 (~RES), IC14.8
unnamed: IC14.9, R13.1
unnamed: IC14.6, IC14.10, R14.2
unnamed: IC14.3, IC14.12
unnamed: IC3.13 (P10), IC14.13
unnamed: IC5.6, IC9.9 (Q), IC15.9 (R3)
unnamed: IC15.16 (R6), R11.2
unnamed: IC15.18 (R7), R10.2
unnamed: IC16.6 (-), R30.1
unnamed: Q1.3 (B), R5.2
unnamed: Q2.3 (B), R4.2
unnamed: Q3.3 (B), R15.2, R16.1
VCC: C1.1, C2.1, C3.1, C4.1, C6.1, C7.1, C8.1, C9.1, C10.1, C11.1, C12.1, C13.1, C15.1, C16.1, C18.1, C23.1, C24.1, C26.1, FL7.3, IC1.24 (VCC), IC2.26 (VCC), IC2.58 (VCC), IC3.7 (VCC), IC3.21 (STBY), IC4.14 (VCC), IC5.14 (VCC), IC6.14 (VCC), IC7.14 (VCC), IC8.14 (VCC), IC9.4 (Sd), IC9.10 (Sd), IC9.14 (VCC), IC10.16 (VCC), IC11.20 (VCC), IC13.20 (VCC), IC15.20 (VCC), IC16.8 (V+), J2.A7 (+5V), J2.A11 (+5V), J2.A15 (+5V), J2.A31 (+5V), J2.A39 (+5V), L2.2, Q4.2 (C), R1.2, R2.1, R3.2, R7.1, R8.1, R10.1, R11.1, R17.2, R18.2, R22.2, R32.2, RA1.1 (common)

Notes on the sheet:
Register 102 bit 0 (CDEN)
Register 102 bit 1 (User defined, used to set I/O address bit A12)
000U 0011
0011 000X
Address 330h OR address 1330h
ID[0] = 00001111 = 0F
ID[1] = 01101100 = 6C
Adapter ID = 6C0F
IRQ9 is Roland's default but may conflict with SCSI on certain PS/2s.

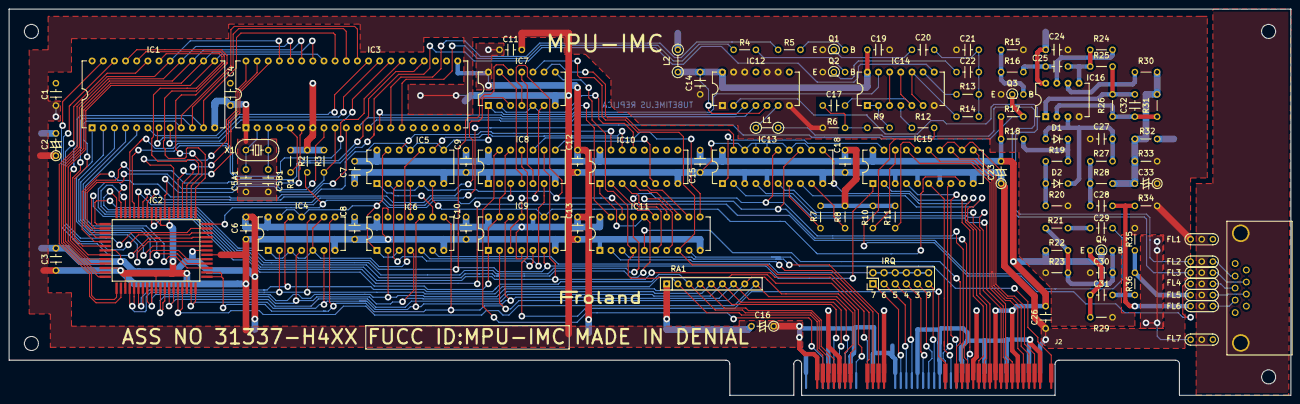
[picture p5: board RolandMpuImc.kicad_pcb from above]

Board: 2 copper layers, 292.1 x 88.0 mm, 110 parts (0 on the bottom side), 157 nets.

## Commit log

2018-10-16 Added files for both cards.
    [RolandMpuImc.csv, RolandMpuImc.kicad_pcb, RolandMpuImc.sch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]
2021-04-15 Fix IC3 pin swap and a few part numbers
    [RolandMpuImc.csv, RolandMpuImc.kicad_pcb, RolandMpuImc.sch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]
